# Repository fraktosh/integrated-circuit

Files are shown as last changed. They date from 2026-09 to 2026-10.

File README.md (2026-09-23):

# entire health platform for extensive wearable sensor data analytics and inference

```python
this entire project started with building a research project on developing local
federated models on health data on the basis of local regions to have sensitivity
or recall towards anomalies. but a device such that doesn't exist that's viable to
do a large scale study on people, so we created the device, FROM SCRATCH.
this project is something that came out of my heart, and everything we developed
is with LOVE, so please support and contribute if you can.

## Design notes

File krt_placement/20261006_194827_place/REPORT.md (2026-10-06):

# Placement report

Board: `input.kicad_pcb` (55 footprint blocks, 4-layer, no copper, outline present).
Verdict: **placement already clean at the P0 gate. No optimizer run. Board shipped unchanged.**

## P0 measurements (copper-free board, floor 0.1 mm from board netclass)

| instrument | result |
|---|---|
| `check_drc` (`--clearance 0.1 --clearance-margin 0`) | 0 violations |
| `check_assembly` | `buildable`, blocking 0, 0 pad pairs, 0 hole conflicts, 0 parts with pad copper off-board |
| `render_placement` `checklist.a_off_outline.pad_copper` | empty |
| `board_score` | blocking 39 = unrouted 39, broken 0, drc 0, assembly 0, undersized 0 |

`blocking 39` is the copper-free baseline: every net is unrouted because no routing exists yet. It is not a placement defect. `placement_blocked` is empty (no net is unroutable because of a part pose).

## Reported, not gated

- Courtyard pair J4 <-> J5: 1.181 mm2, depth 0.638 mm, front side. Marked COURTYARD-BLOCKING by census but report-only (no moved-vs-baseline, nothing moved). Bodies do not overlap (`b_body_overlap_pairs` empty); pads clear.
- Courtyard off outline: J2 by 1.07 mm, J4 by 0.12 mm. Pad copper is all inside the outline. Likely edge connectors (J2 has CC1/CC2, USB-C).
- crossings 511, hpwl 762.8 (informational).
- 7 rail-sharing decaps lie beyond the 5 mm search radius (worst 9.2 mm); decap grading skipped for them.
- No design brief, no intent. Floorplan ungraded.

## Decision

Non-negotiable 1: measured clean means STOP. A quench over a placement that passes risks making it worse. If J4/J5 courtyard contact or J2 overhang matters mechanically, declare it in a `.design-brief.json` / intent `overlap_waivers` or fix by hand with `place_pose.py`. Not changed here because no instrument shows it harming routing or buildability.

## Artifacts

- `final.kicad_pcb` + `final.kicad_pro` (+ `.kicad_prl`): byte copy of input via `copy_board.py`.
- `ledger.jsonl`: one entry, stop condition 1.
- `wk/`: drc0.json, assembly0.json, render0.json/png, score0.json, intent0.json, venv.
- Movie: not produced. No lap moved a part, so a film would show one static frame.

## Environment note

System Python lacked numpy/scipy/shapely/Pillow. A venv was created inside `wk/venv` to avoid touching files outside the work dir.

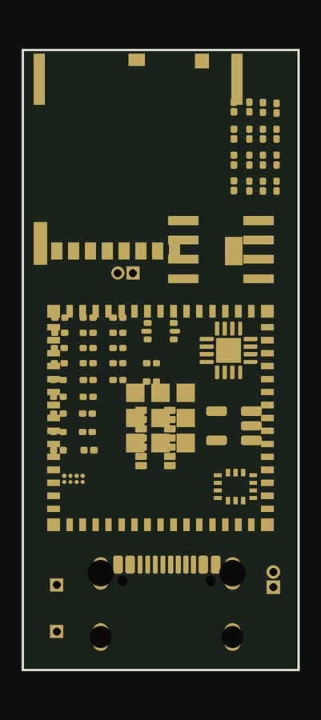
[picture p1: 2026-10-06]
krt_placement/20261006_194827_place/_gui_preview/final.png

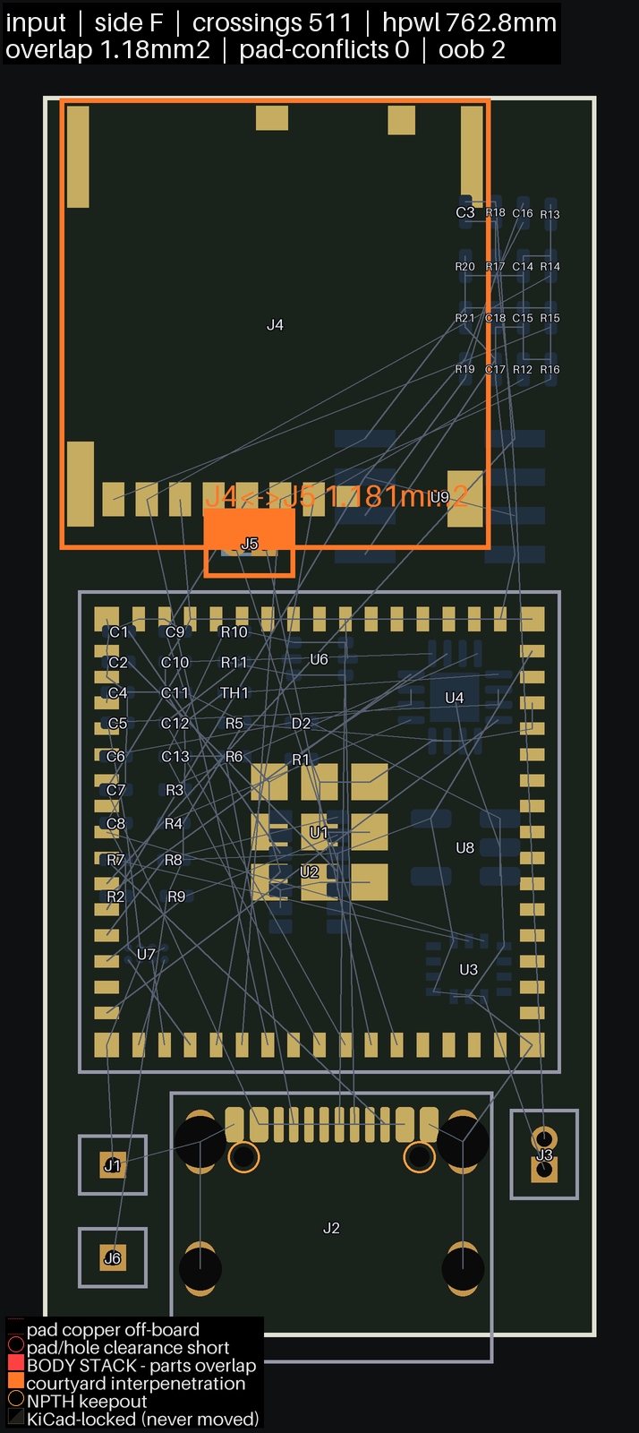
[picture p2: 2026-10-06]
krt_placement/20261006_194827_place/wk/render0_F.png

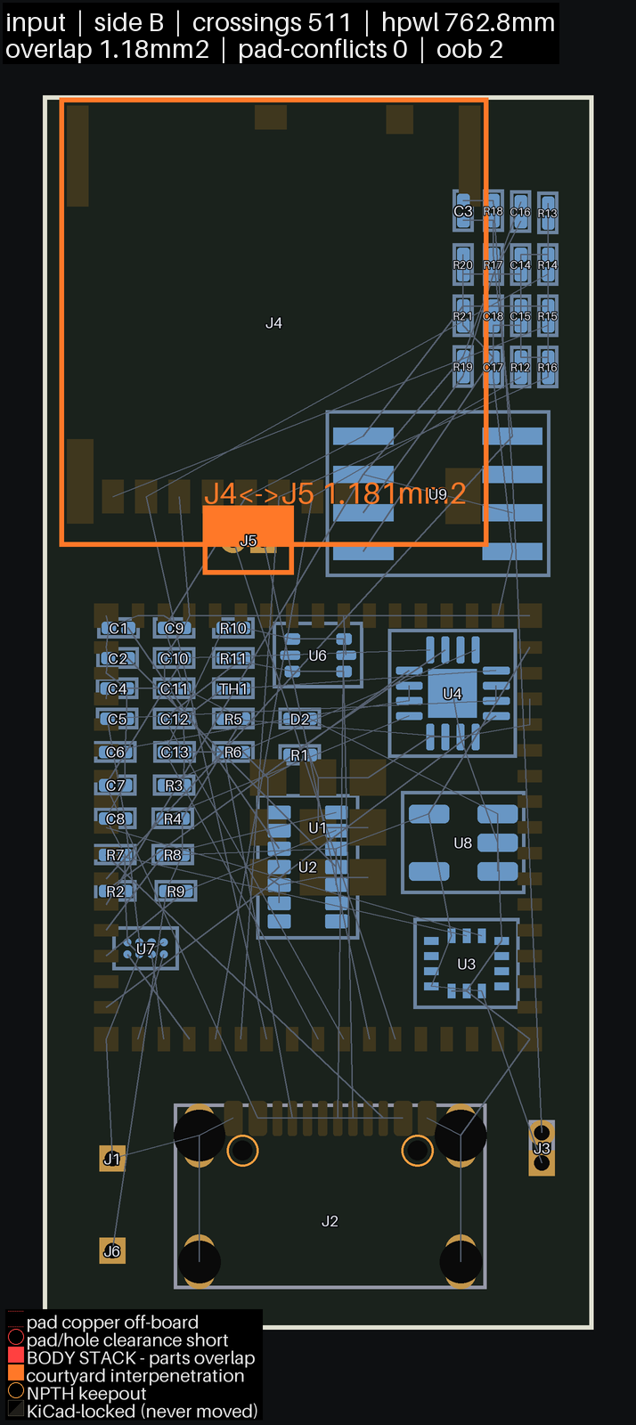
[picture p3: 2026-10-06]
krt_placement/20261006_194827_place/wk/render0_B.png

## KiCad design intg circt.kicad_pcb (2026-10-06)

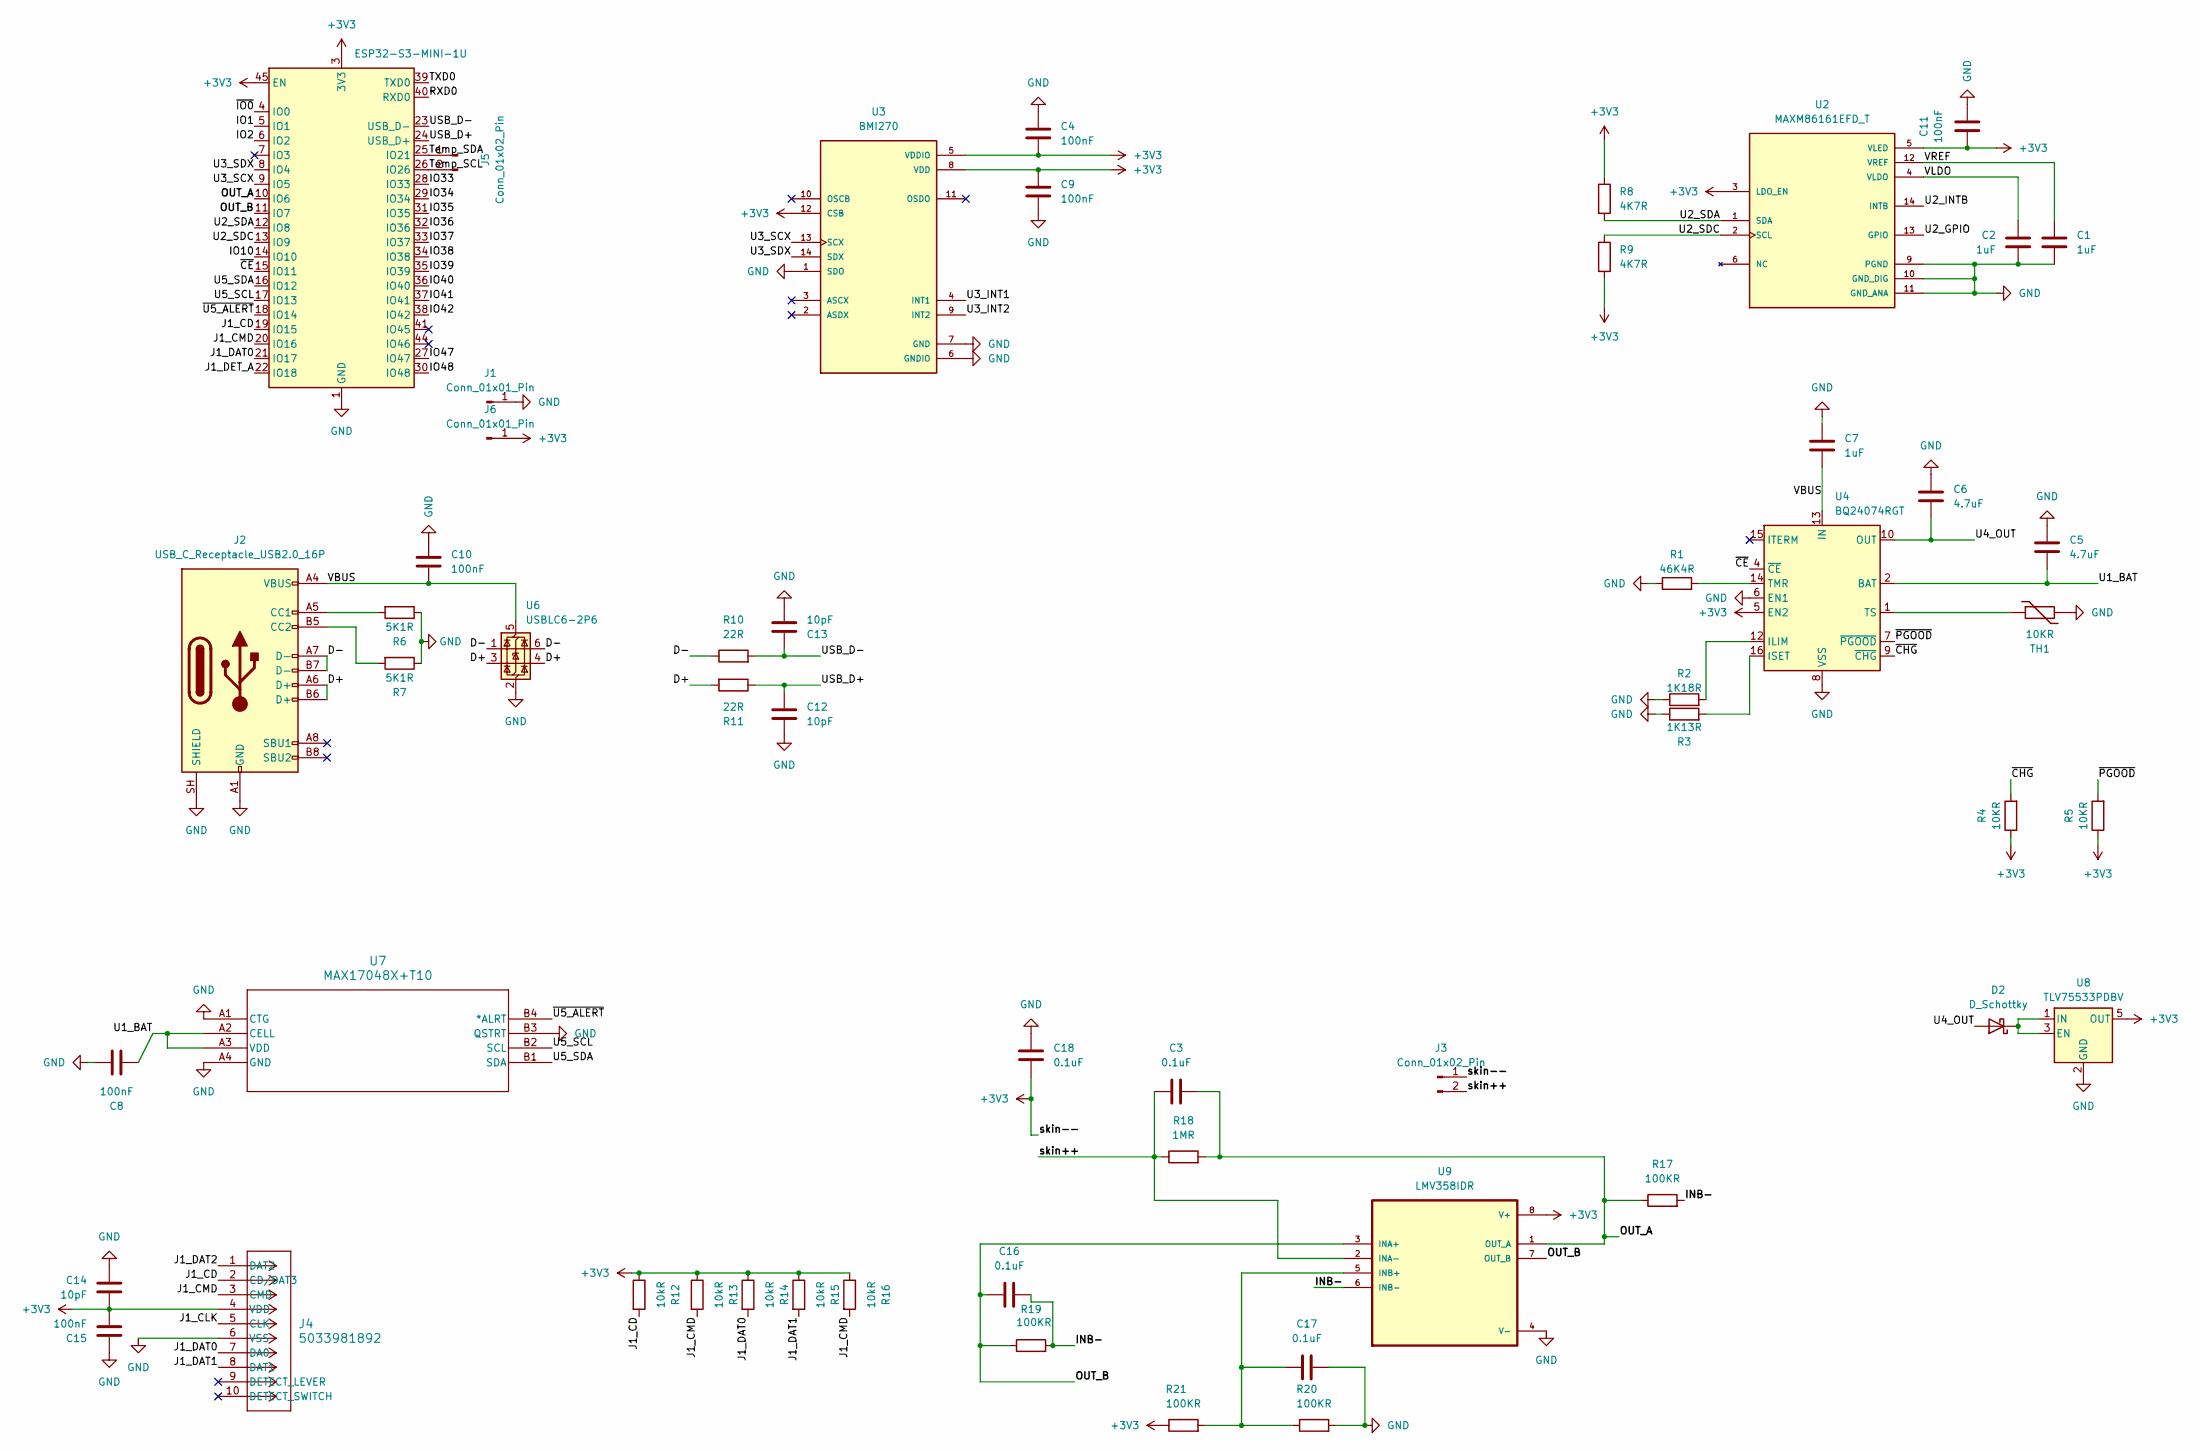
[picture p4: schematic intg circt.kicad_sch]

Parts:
C1, C2, C7: 1uF; C_0201_0603Metric
C3, C16, C17, C18: 0.1uF; C_0201_0603Metric
C4, C8, C9, C10, C11, C15: 100nF; C_0201_0603Metric
C5, C6: 4.7uF; C_0201_0603Metric
C12, C13, C14: 10pF; C_0201_0603Metric
D2: D_Schottky; D_0201_0603Metric
J1, J6: Conn_01x01_Pin; PinHeader_1x01_P1.00mm_Vertical
J2: USB_C_Receptacle_USB2.0_16P; USB_C_Receptacle_GCT_USB4105-xx-A_16P_TopMnt_Horizontal
J3, J5: Conn_01x02_Pin; PinHeader_1x02_P1.00mm_Vertical
J4: 5033981892; CONN_503398-1892_MOL
R1: 46K4R; R_0201_0603Metric
R2: 1K18R; R_0201_0603Metric
R3: 1K13R; R_0201_0603Metric
R4, R5: 10KR; R_0201_0603Metric
R6, R7: 5K1R; R_0201_0603Metric
R8, R9: 4K7R; R_0201_0603Metric
R10, R11: 22R; R_0201_0603Metric
R12, R13, R14, R15, R16: 10kR; R_0201_0603Metric
R17, R19, R20, R21: 100KR; R_0201_0603Metric
R18: 1MR; R_0201_0603Metric
TH1: 10KR; R_0201_0603Metric
U1: ESP32-S3-MINI-1U; ESP32-S2-MINI-1U
U2: MAXM86161EFD_T; PSON60P430X290X150-14N; PARTREV 1
U3: BMI270; XDCR_BMI270
U4: BQ24074RGT; VQFN-16-1EP_3x3mm_P0.5mm_EP1.6x1.6mm
U6: USBLC6-2P6; SOT-666
U7: MAX17048X+T10; 21-0555B_W80B1-1_MXM
U8: TLV75533PDBV; SOT-23-5
U9: LMV358IDR

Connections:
+3V3: C4.2, C9.2, C11.1, C14.1, C15.1, C18.1, J3.1, J4.4 (VDD), J6.1 (Pin_1_1), R4.1, R5.1, R8.1, R9.2, R12.1, R13.1, R14.1, R15.1, R16.1, R21.1, U1.3 (3V3), U1.45 (EN), U2.3 (LDO_EN), U2.5 (VLED), U3.5 (VDDIO), U3.8 (VDD), U3.12 (CSB), U4.5 (EN2), U8.5 (OUT), U9.8 (V+)
/D+: J2.A6 (D+), J2.B6 (D+), R11.2, U6.3 (I/O2), U6.4 (I/O2)
/D-: J2.A7 (D-), J2.B7 (D-), R10.1, U6.1 (I/O1), U6.6 (I/O1)
/INB-: C16.2, R17.2, R19.2, U9.6 (INB-)
/IO1: U1.5 (IO1)
/IO2: U1.6 (IO2)
/IO10: U1.14 (IO10)
/IO33: U1.28 (IO33)
/IO34: U1.29 (IO34)
/IO35: U1.31 (IO35)
/IO36: U1.32 (IO36)
/IO37: U1.33 (IO37)
/IO38: U1.34 (IO38)
/IO39: U1.35 (IO39)
/IO40: U1.36 (IO40)
/IO41: U1.37 (IO41)
/IO42: U1.38 (IO42)
/IO47: U1.27 (IO47)
/IO48: U1.30 (IO48)
/J1_CD: J4.2 (CD/DAT3), R12.2, U1.19 (IO15)
/J1_CLK: J4.5 (CLK)
/J1_CMD: J4.3 (CMD), R13.2, R16.2, U1.20 (IO16)
/J1_DAT0: J4.7 (DA0), R14.2, U1.21 (IO17)
/J1_DAT1: J4.8 (DAT1), R15.2
/J1_DAT2: J4.1 (DAT2)
/J1_DET_A: U1.22 (IO18)
/OUT_A: C3.2, R17.1, R18.2, U1.10 (IO6), U9.1 (OUT_A)
/OUT_B: C16.1, R19.1, U1.11 (IO7), U9.3 (INA+), U9.7 (OUT_B)
/RXD0: U1.40 (RXD0)
/TXD0: U1.39 (TXD0)
/Temp_SCL: J5.2, U1.26 (IO26)
/Temp_SDA: J5.1, U1.25 (IO21)
/U1_BAT: C5.2, C8.1, U4.2 (BAT), U4.3 (BAT), U7.A2 (CELL), U7.A3 (VDD)
/U2_GPIO: U2.13 (GPIO)
/U2_INTB: U2.14 (INTB)
/U2_SDA: R8.2, U1.12 (IO8), U2.1 (SDA)
/U2_SDC: R9.1, U1.13 (IO9), U2.2 (SCL)
/U3_INT1: U3.4 (INT1)
/U3_INT2: U3.9 (INT2)
/U3_SCX: U1.9 (IO5), U3.13 (SCX)
/U3_SDX: U1.8 (IO4), U3.14 (SDX)
/U4_OUT: C6.2, D2.2 (A), U4.10 (OUT), U4.11 (OUT)
/U5_SCL: U1.17 (IO13), U7.B2 (SCL)
/U5_SDA: U1.16 (IO12), U7.B1 (SDA)
/USB_D+: C12.2, R11.1, U1.24 (USB_D+)
/USB_D-: C13.2, R10.2, U1.23 (USB_D-)
/VBUS: C7.2, C10.1, J2.A4 (VBUS), J2.A9 (VBUS), J2.B4 (VBUS), J2.B9 (VBUS), U4.13 (IN), U6.5 (VBUS)
/VLDO: C2.1, U2.4 (VLDO)
/VREF: C1.1, U2.12 (VREF)
/skin++: C3.1, J3.2, R18.1, U9.2 (INA-)
/~CE: U1.15 (IO11), U4.4 (~CE)
/~CHG: R4.2, U4.9 (~CHG)
/~IO0: U1.4 (IO0)
/~PGOOD: R5.2, U4.7 (~PGOOD)
/~U5_ALERT: U1.18 (IO14), U7.B4 (*ALRT)
GND: C1.2, C2.2, C4.1, C5.1, C6.1, C7.1, C8.2, C9.1, C10.2, C11.2, C12.1, C13.1, C14.2, C15.2, C17.2, C18.2, J1.1 (Pin_1_1), J2.A1 (GND), J2.A12 (GND), J2.B1 (GND), J2.B12 (GND), J2.SH (SHIELD), J4.6 (VSS), R1.1, R2.1, R3.1, R6.1, R7.1, R20.2, TH1.2, U1.1 (GND), U1.2 (GND), U1.42 (GND), U1.43 (GND), U1.46 (GND), U1.47 (GND), U1.48 (GND), U1.49 (GND), U1.50 (GND), U1.51 (GND), U1.52 (GND), U1.53 (GND), U1.54 (GND), U1.55 (GND), U1.56 (GND), U1.57 (GND), U1.58 (GND), U1.59 (GND), U1.60 (GND), U1.61 (GND), U1.62 (GND), U1.63 (GND), U1.64 (GND), U1.65 (GND), U2.9 (PGND), U2.10 (GND_DIG), U2.11 (GND_ANA), U3.1 (SDO), U3.6 (GNDIO), U3.7 (GND), U4.6 (EN1), U4.8 (VSS), U4.17 (VSS), U6.2 (GND), U7.A1 (CTG), U7.A4 (GND), U7.B3 (QSTRT), U8.2 (GND), U9.4 (V-)
unnamed: D2.1 (K), U8.1 (IN), U8.3 (EN)
unnamed: J2.A5 (CC1), R6.2
unnamed: J2.B5 (CC2), R7.2
unnamed: R2.2, U4.12 (ILIM)
unnamed: R3.2, U4.16 (ISET)
unnamed: R1.2, U4.14 (TMR)
unnamed: TH1.1, U4.1 (TS)
unnamed: C17.1, R20.1, R21.2, U9.5 (INB+)

Board: 4 copper layers, 55 parts (49 on the bottom side), 39 nets, no tracks yet.

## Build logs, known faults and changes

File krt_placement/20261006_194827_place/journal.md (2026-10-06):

# Journal
- P0: no copper (0 segments, 0 vias; keepout "vias not_allowed" and zone_connect lines are rules, not copper).
- Created wk/venv (numpy, scipy, shapely, Pillow, imageio) because system python lacked numpy.
- check_assembly buildable; check_drc 0; pad copper off-outline 0.
- Verdict clean -> no P2..P5. final = copy of input.
- Ledger entry recorded (stop 1). No movie (no moves).

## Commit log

2026-09-22 Commit existing project to new account
    [intg circt.kicad_pcb, intg circt.kicad_sch]
2026-09-22 Add placeholder file to track empty folder
2026-09-22 ye ye change kiya hai maine dekhlo
    [intg circt.kicad_sch]
2026-09-23 just tested if it works, it does i think
    [intg circt.kicad_pcb]
2026-09-25 temp sensor added, sd card schematic done, recheck.
    [intg circt.kicad_sch]
2026-09-29 I HAVE ADDED THE EDA SENSOR
    [intg circt.kicad_pcb, intg circt.kicad_sch]
2026-09-30 new library
    [intg circt.kicad_pcb, intg circt.kicad_sch]
2026-10-06 change so much
    [intg circt.kicad_pcb, intg circt.kicad_sch]
2026-10-06 placement and routing
    [board.kicad_pcb, final.kicad_pcb, input.kicad_pcb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]
2026-10-06 route maxing
    [intg circt.kicad_pcb]

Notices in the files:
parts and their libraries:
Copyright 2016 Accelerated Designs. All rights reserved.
